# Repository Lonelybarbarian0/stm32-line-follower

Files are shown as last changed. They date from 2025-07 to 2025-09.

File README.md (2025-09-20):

# stm32-line-follower
An advanced line follower based on STM32F446RE. This design consists of 12 Analog IR sensors (CNY70) , a dual H-bridge driver (TB6612FNG) , has I2C ports for oled display , push buttons , 12V battery accomodation , SWD , and debug UART ports for programming and debugging the microcontroller.
Has two voltage regulators for 3V3 and 5V.

It has mounting holes for caster wheel (15mm) , specifically this one: https://robu.in/product/mini-3pi-car-n20-caster-robot-ball-wheel/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

It also has mounting holes for adding both N20 (18mm) as well as 14mm * 16mm motor brackets like:https://roboticsdna.in/product/25mm-dc-gear-motor-block-l-shape-motor-bracket/?src=google&kwd=&adgroup={adgroup}&device=c&campaign={campaign}&adgroup={adgroup}&keyword=&matchtype=&gad_source=1&gad_campaignid=22793537991&gbraid=0AAAAAC-xzeH1j9IDTkCSxU-zOjWUDu6ZW&gclid=Cj0KCQjwm93DBhD_ARIsADR_DjG1hGDh40R1bVBjp1YW7XD5IBcDVYip5r4QT6sreYXs5M1MaoTtmnkaAhj5EALw_wcB

Features power on led , a power on switch etc...

SIDE VIEW:
line_follow_stm_NV

BACK VIEW:
line_follow_stm_BV

PIN CONFIG:
line_follow

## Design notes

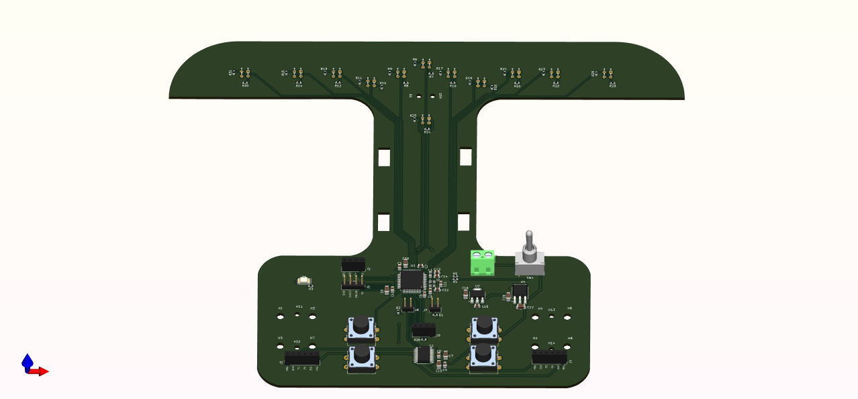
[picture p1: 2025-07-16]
stm32 line follower/line_follow_stm_NV.png

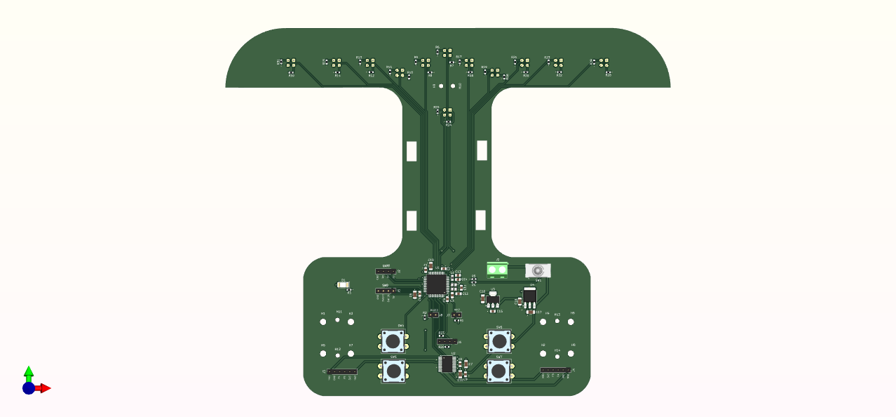
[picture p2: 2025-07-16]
stm32 line follower/line_follow_stm_FV.png

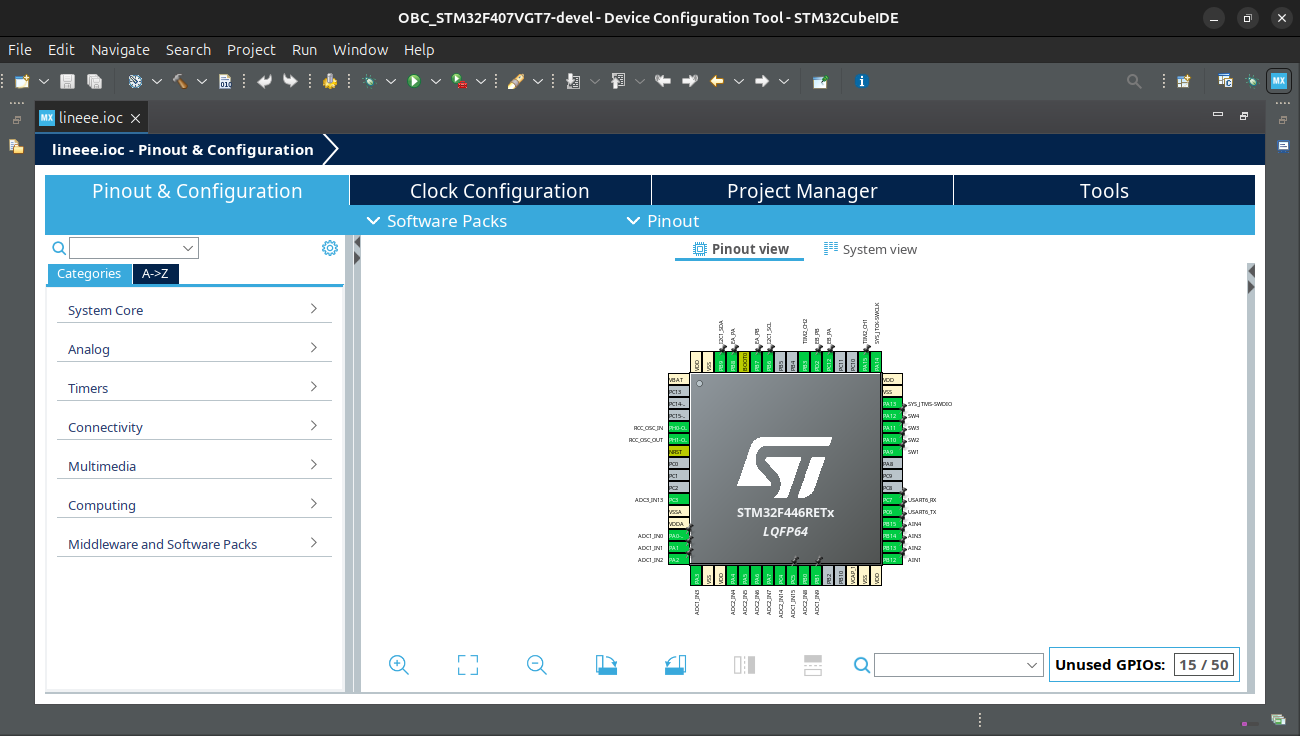
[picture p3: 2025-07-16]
stm32 line follower/line_follow.png

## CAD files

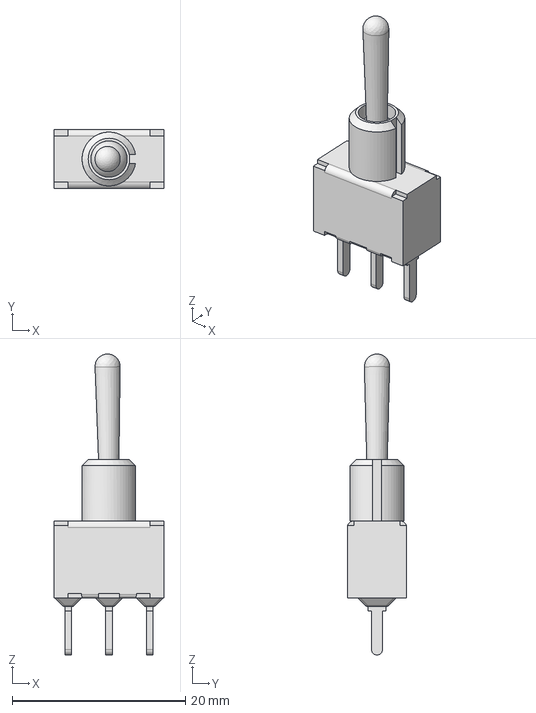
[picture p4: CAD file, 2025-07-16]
stm32 line follower/line_follow_stm/footprint_libraries/100SP1T1B4M2QE/100SP1T1B4M2QE.step
12.7 x 6.86 x 34.8 mm

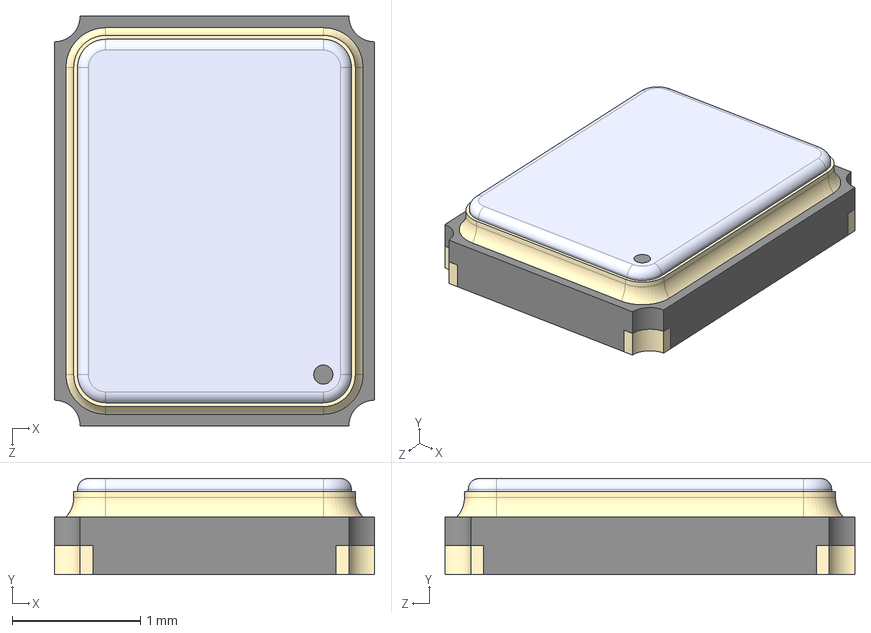
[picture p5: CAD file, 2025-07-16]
stm32 line follower/line_follow_stm/footprint_libraries/C3E_8_000_18_1020_X_R/C3E-8.000-18-1020-X-R.step
2.50 x 0.75 x 3.20 mm

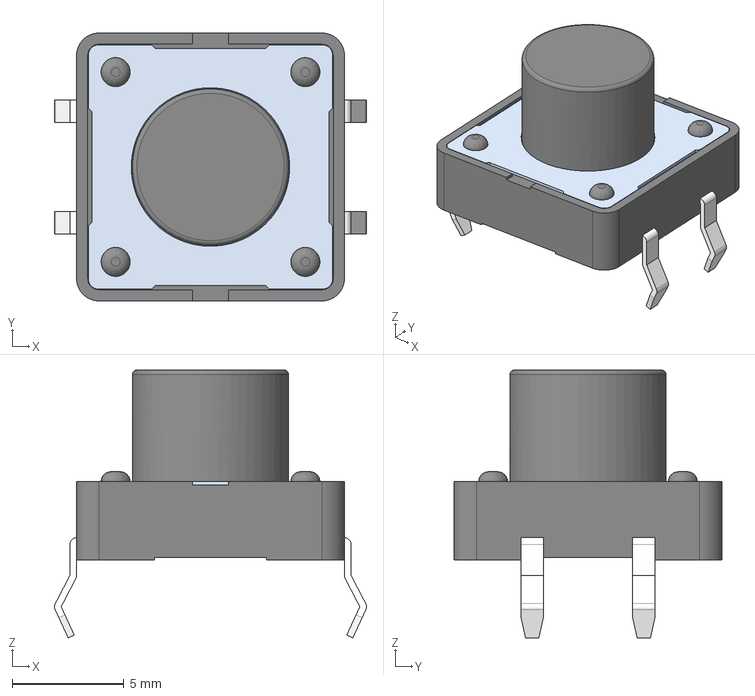
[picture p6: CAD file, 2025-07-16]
stm32 line follower/line_follow_stm/3D Models/430476085716+(rev1).stp
14.0 x 12.0 x 12.0 mm

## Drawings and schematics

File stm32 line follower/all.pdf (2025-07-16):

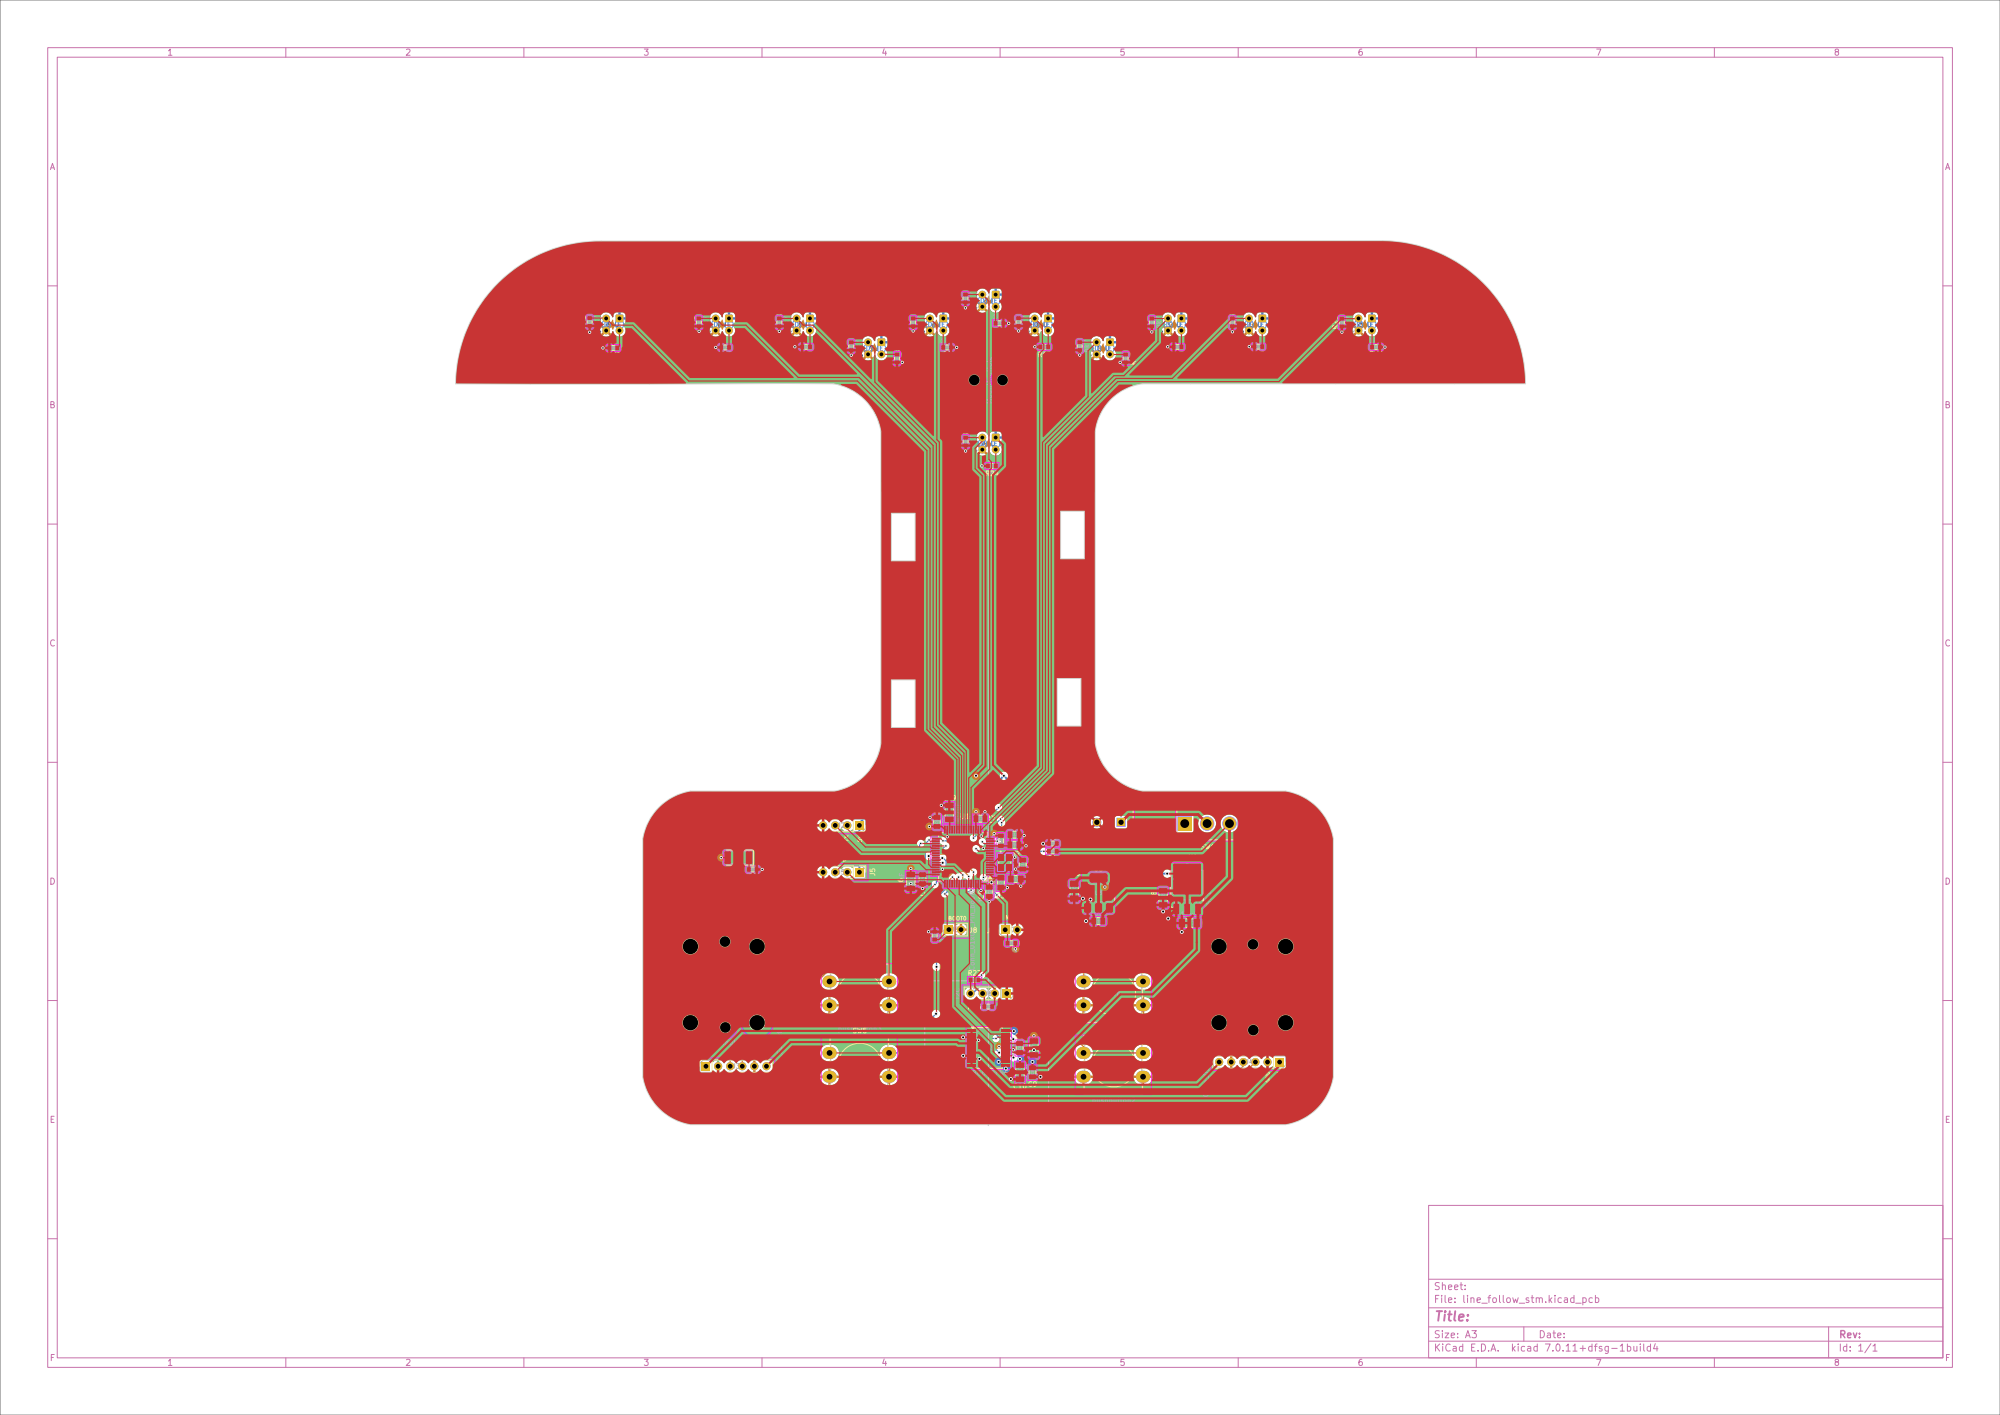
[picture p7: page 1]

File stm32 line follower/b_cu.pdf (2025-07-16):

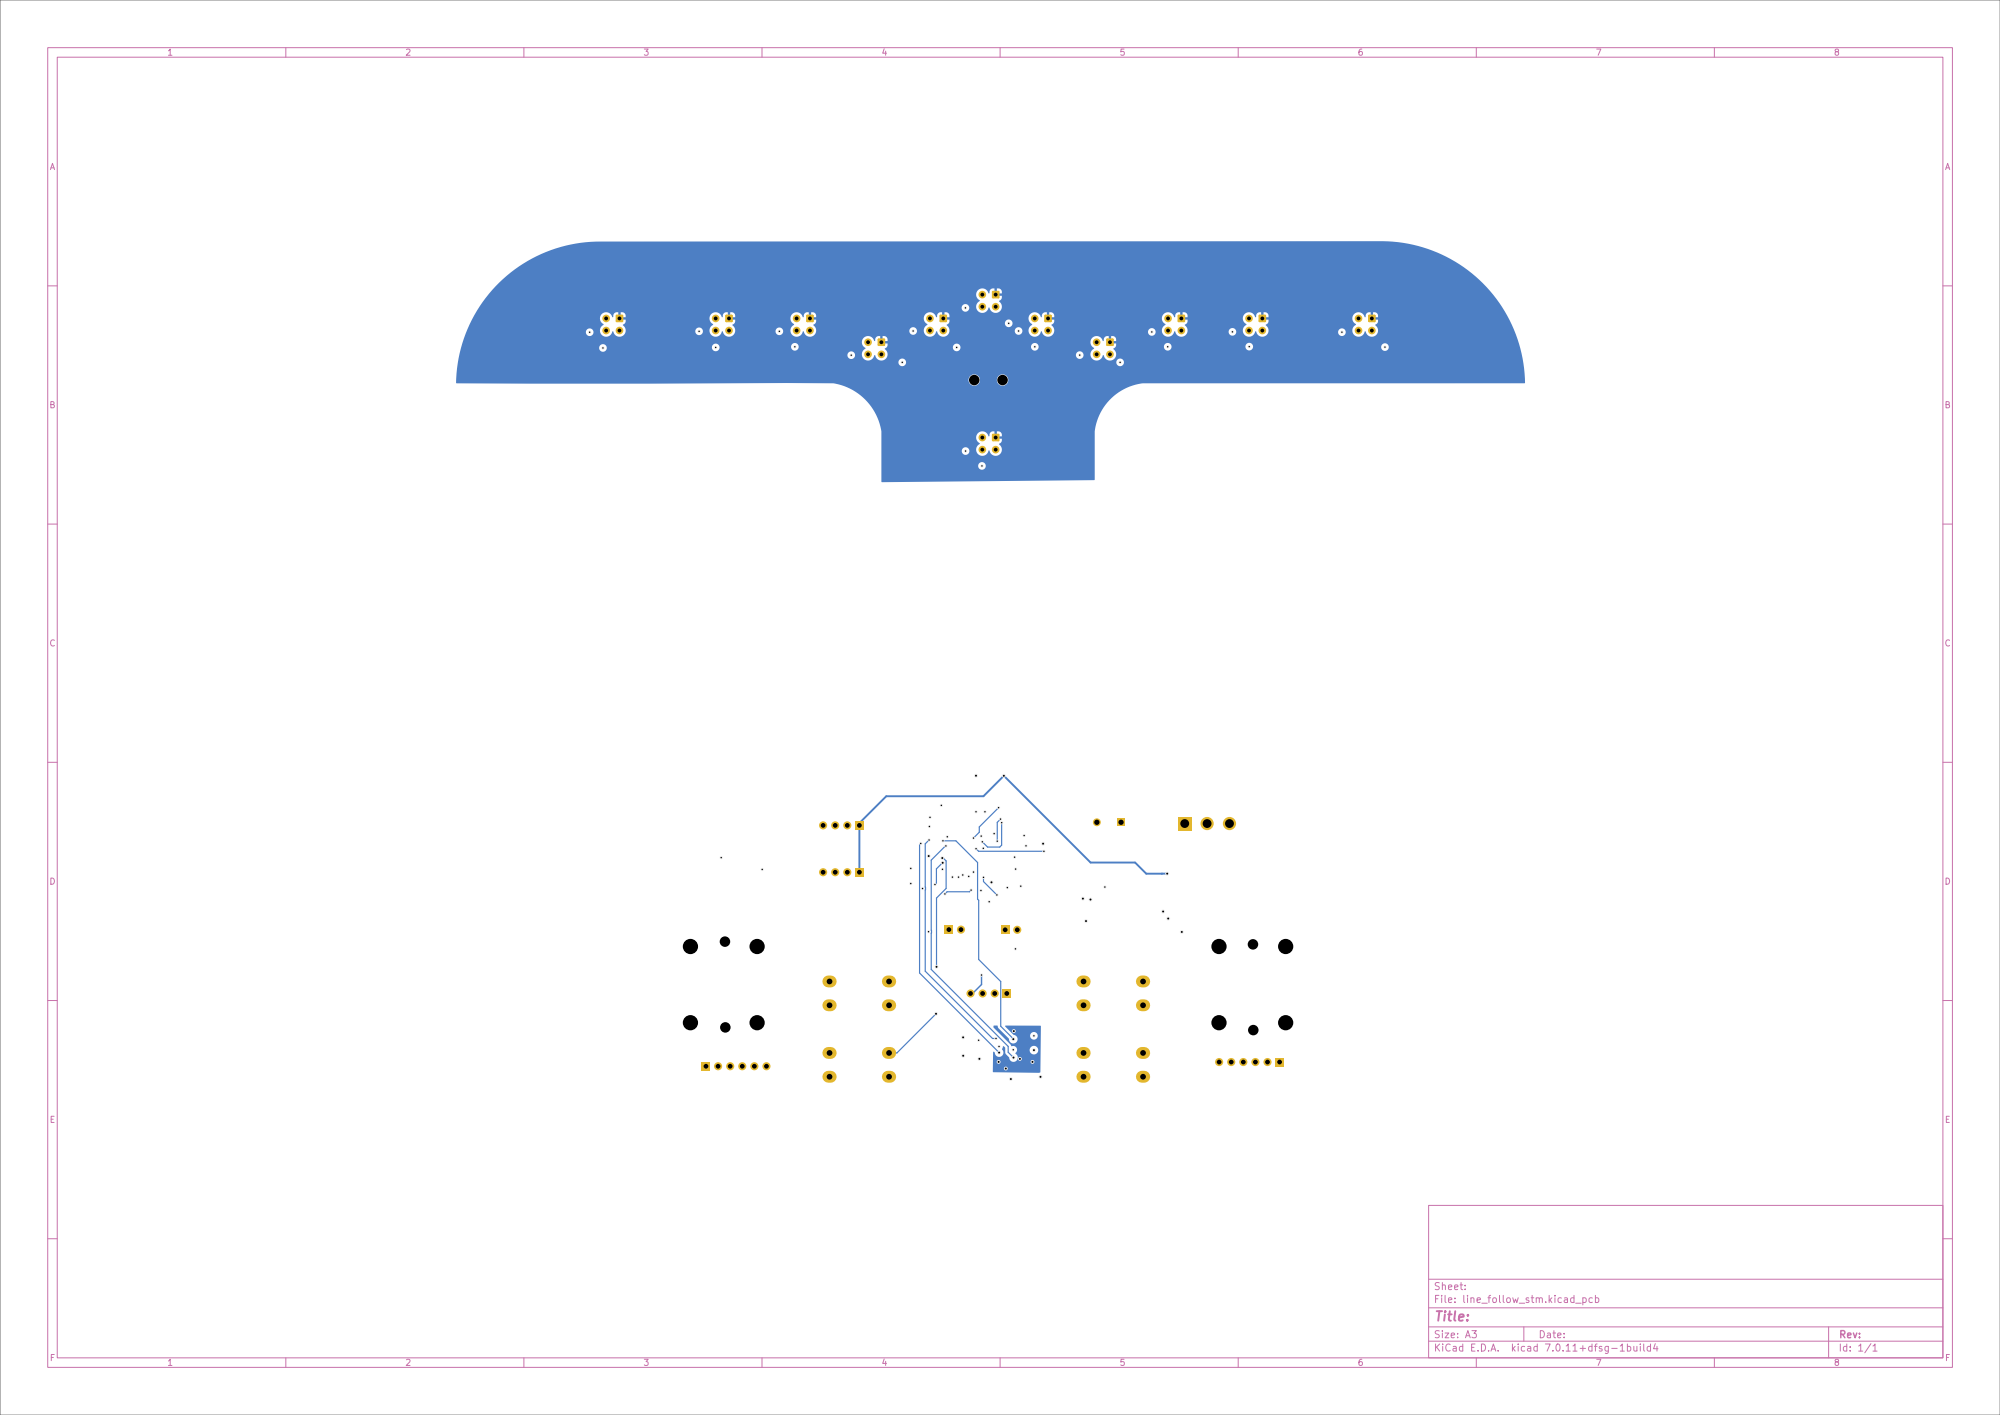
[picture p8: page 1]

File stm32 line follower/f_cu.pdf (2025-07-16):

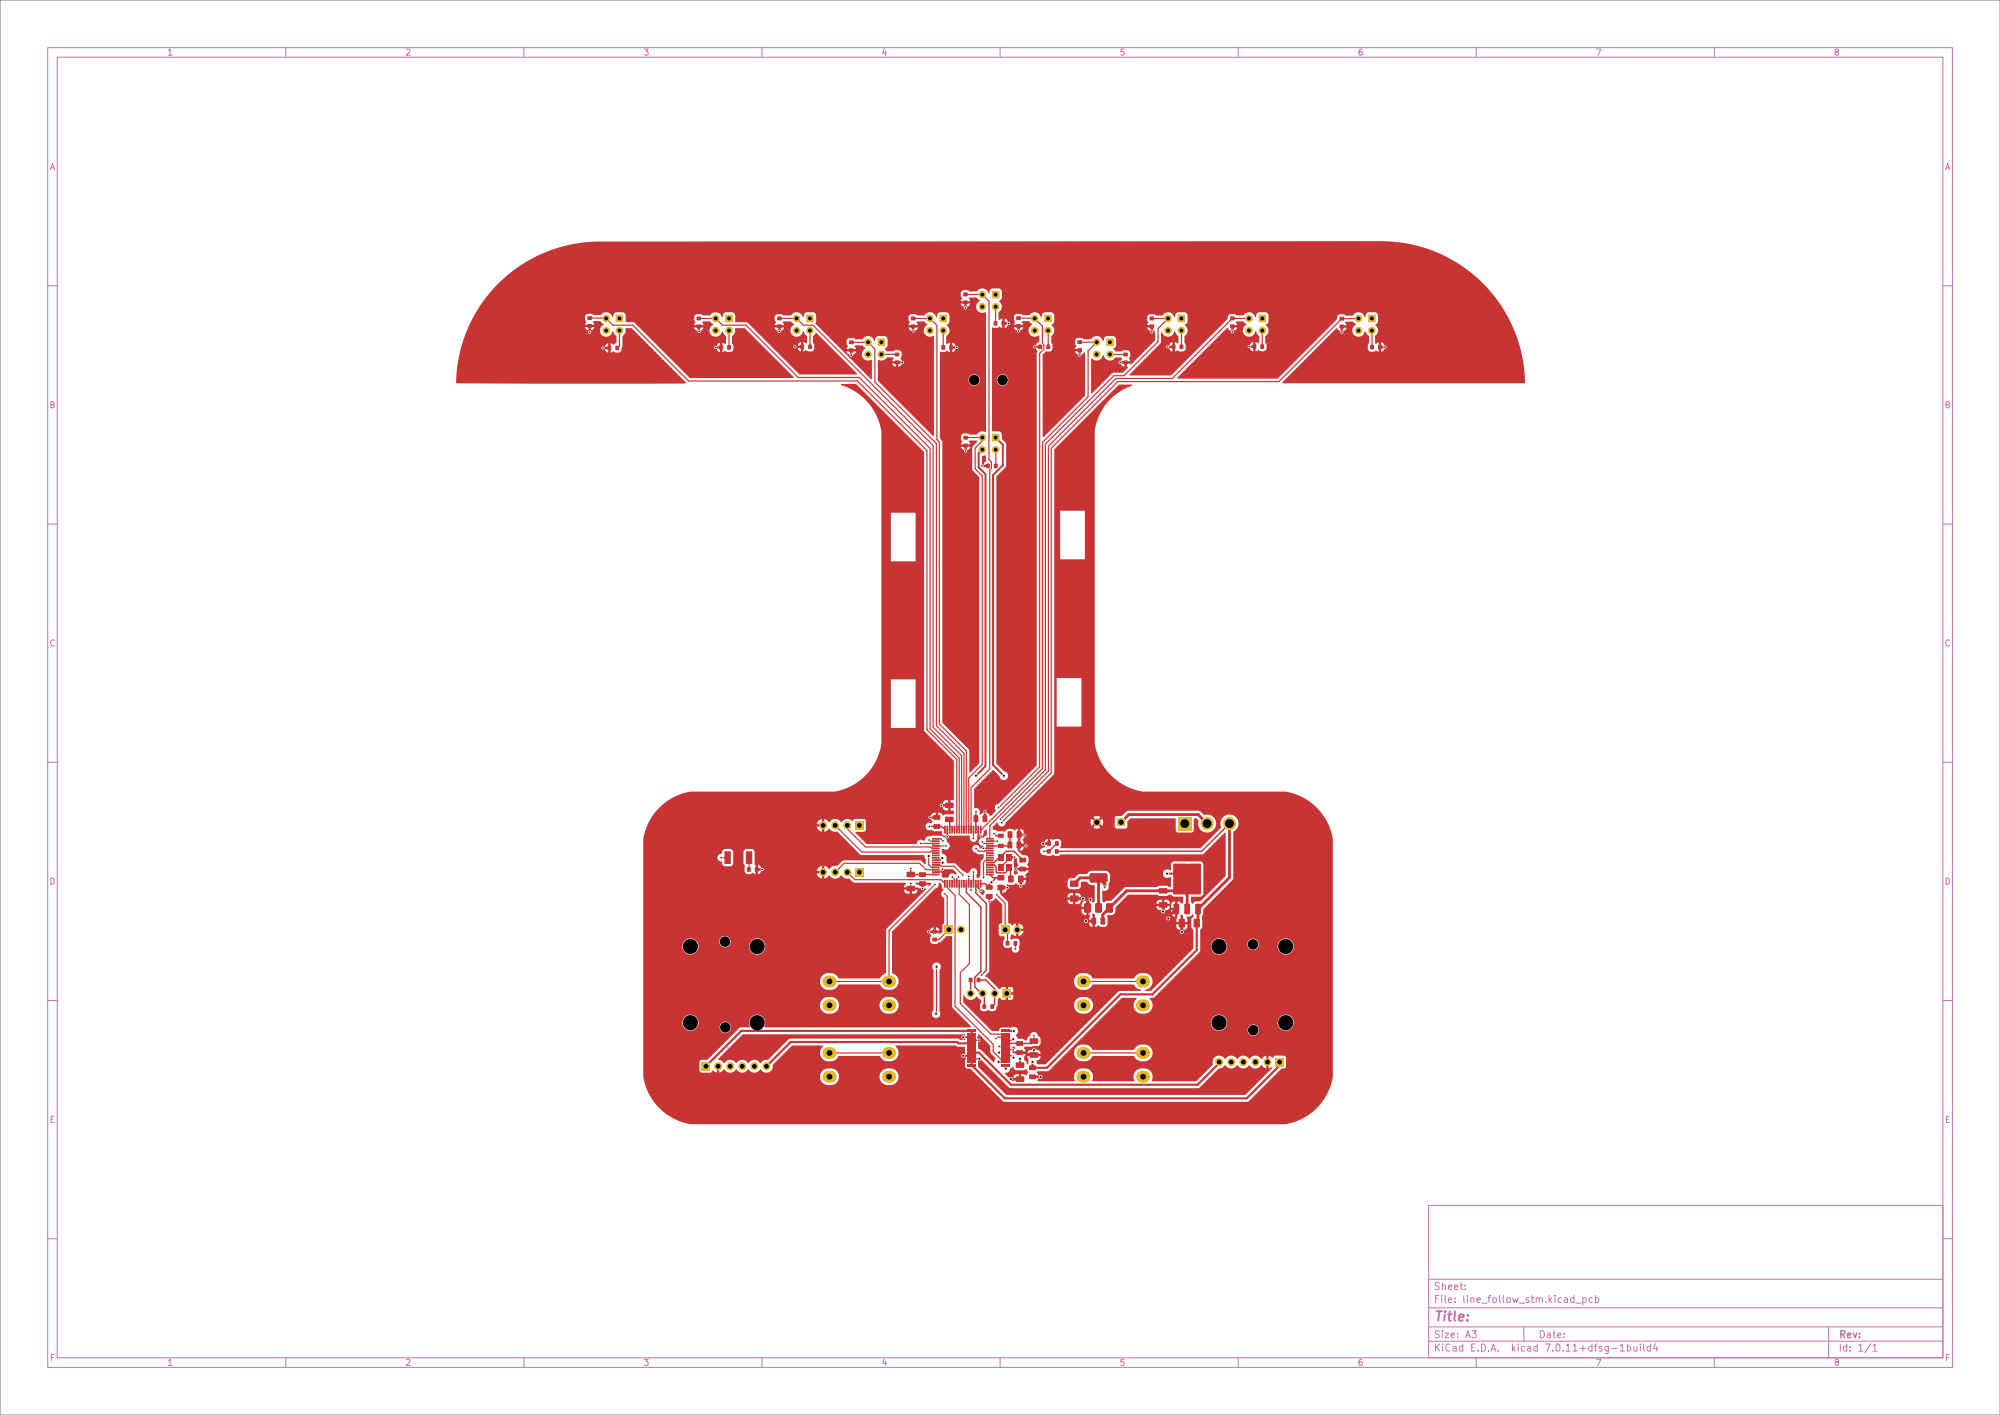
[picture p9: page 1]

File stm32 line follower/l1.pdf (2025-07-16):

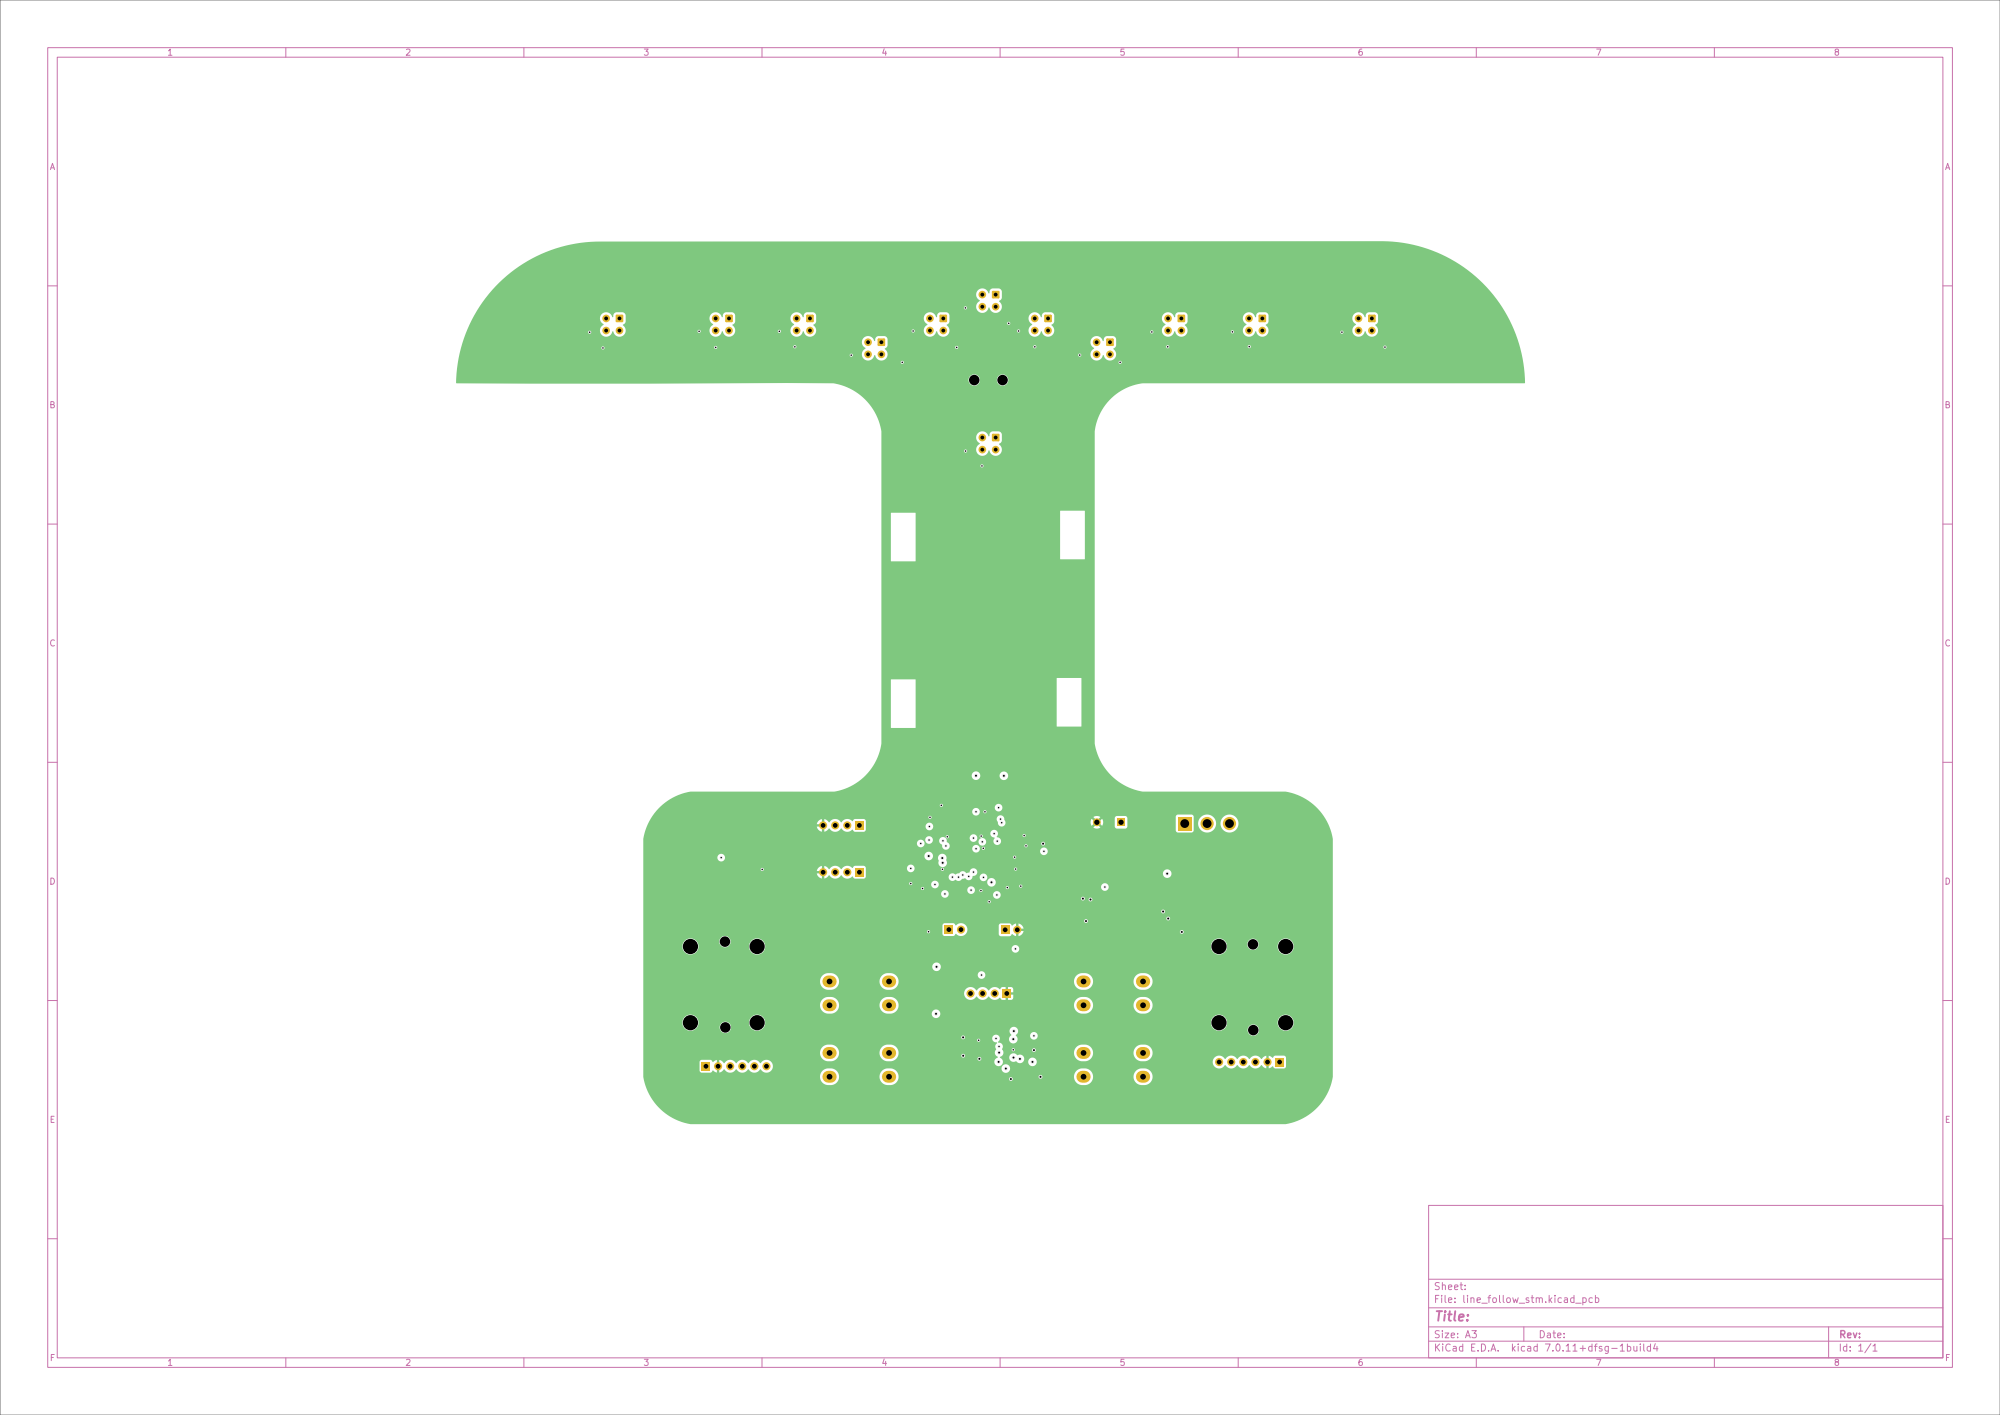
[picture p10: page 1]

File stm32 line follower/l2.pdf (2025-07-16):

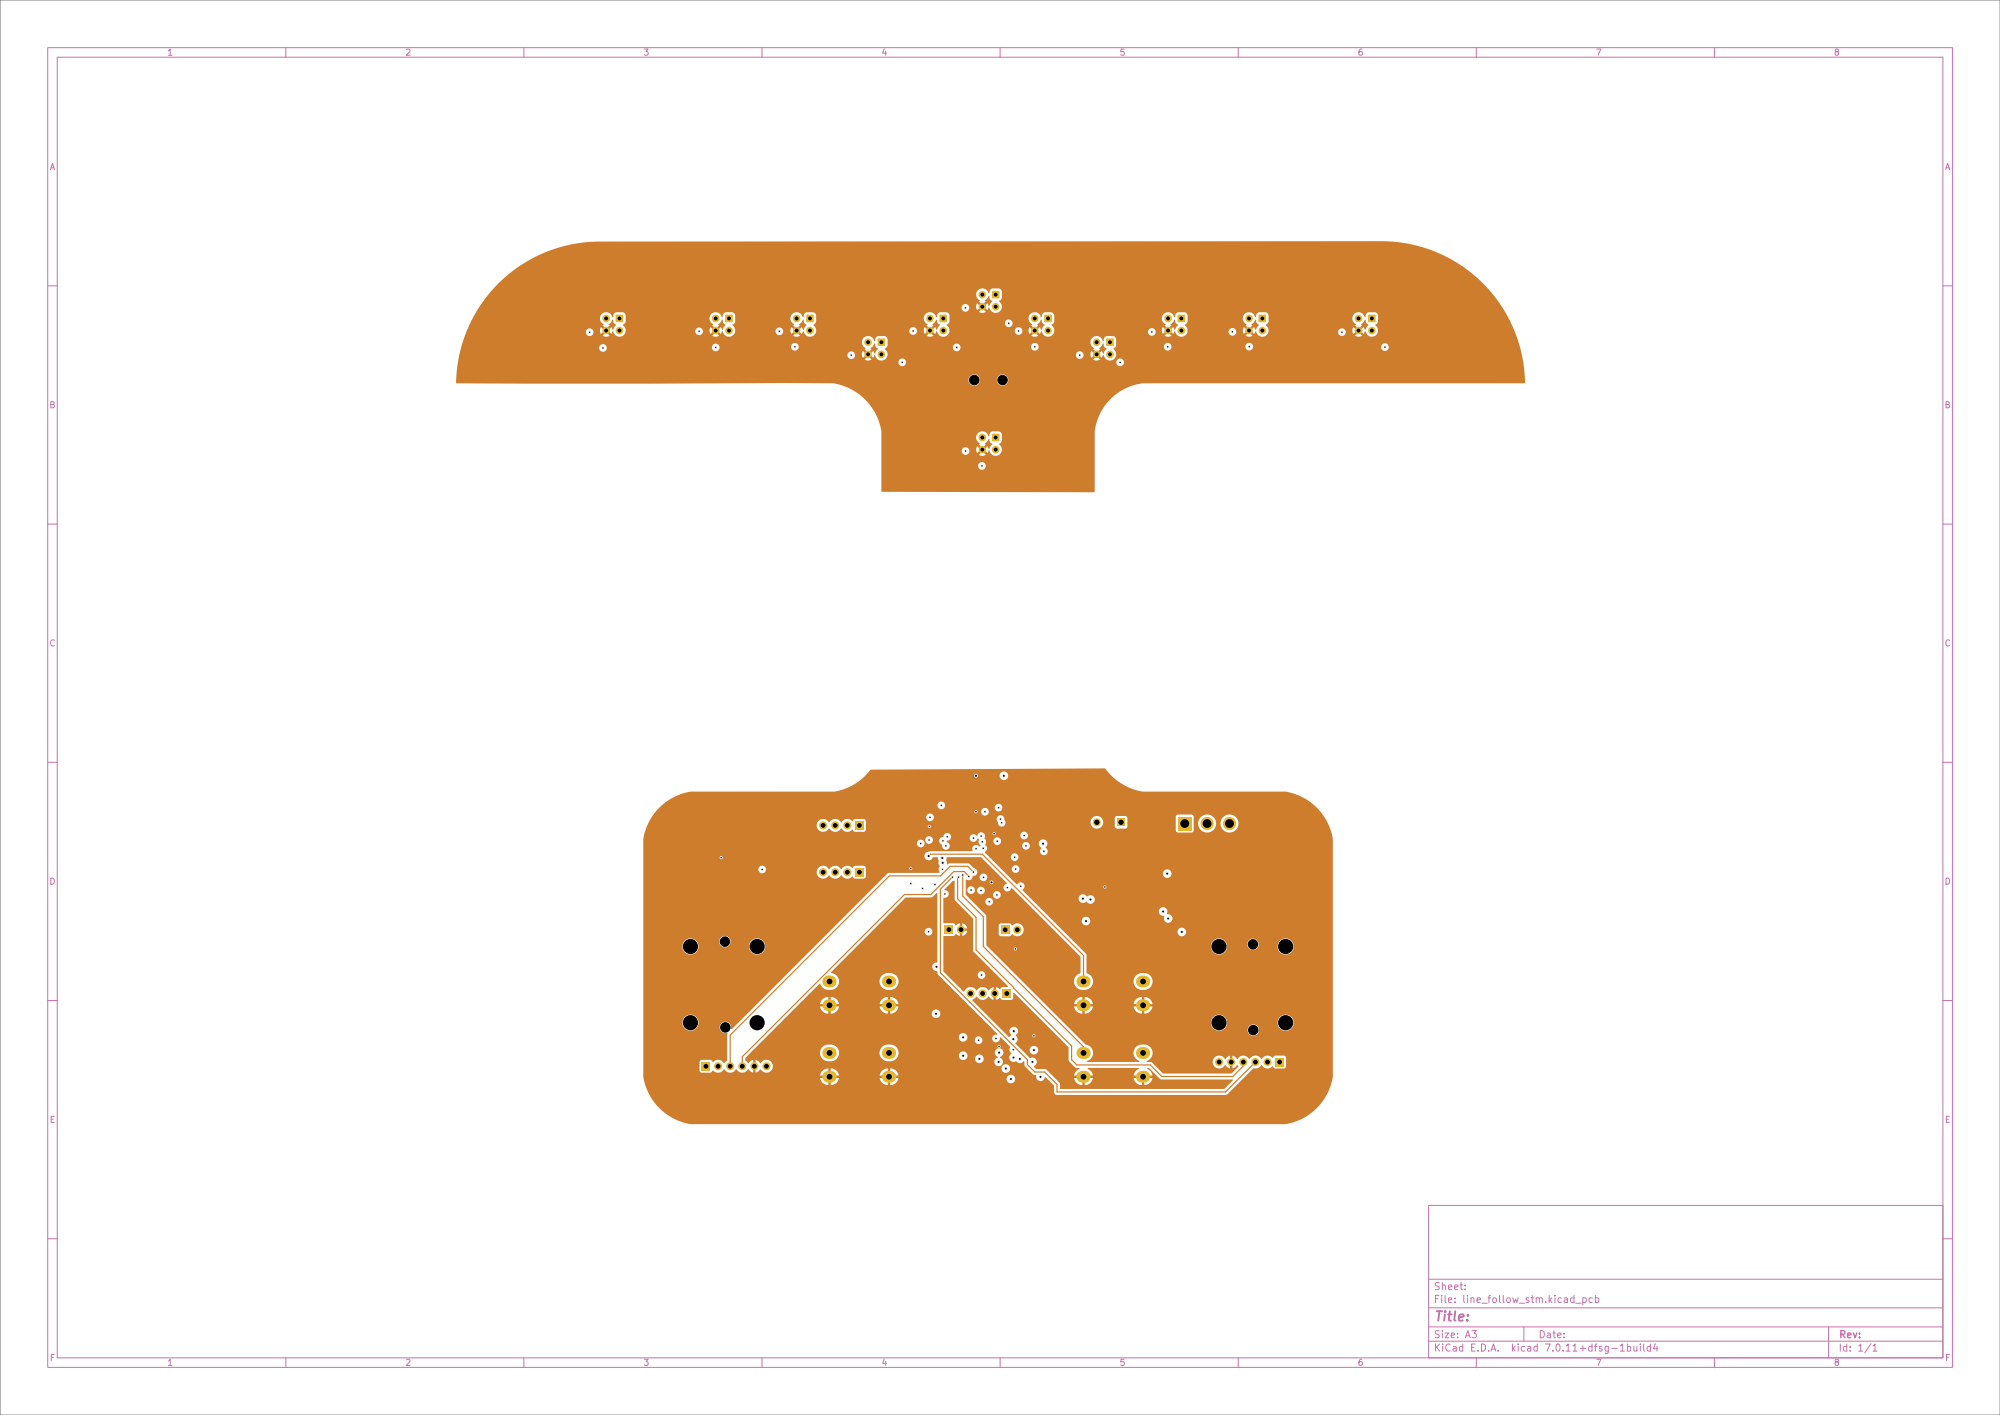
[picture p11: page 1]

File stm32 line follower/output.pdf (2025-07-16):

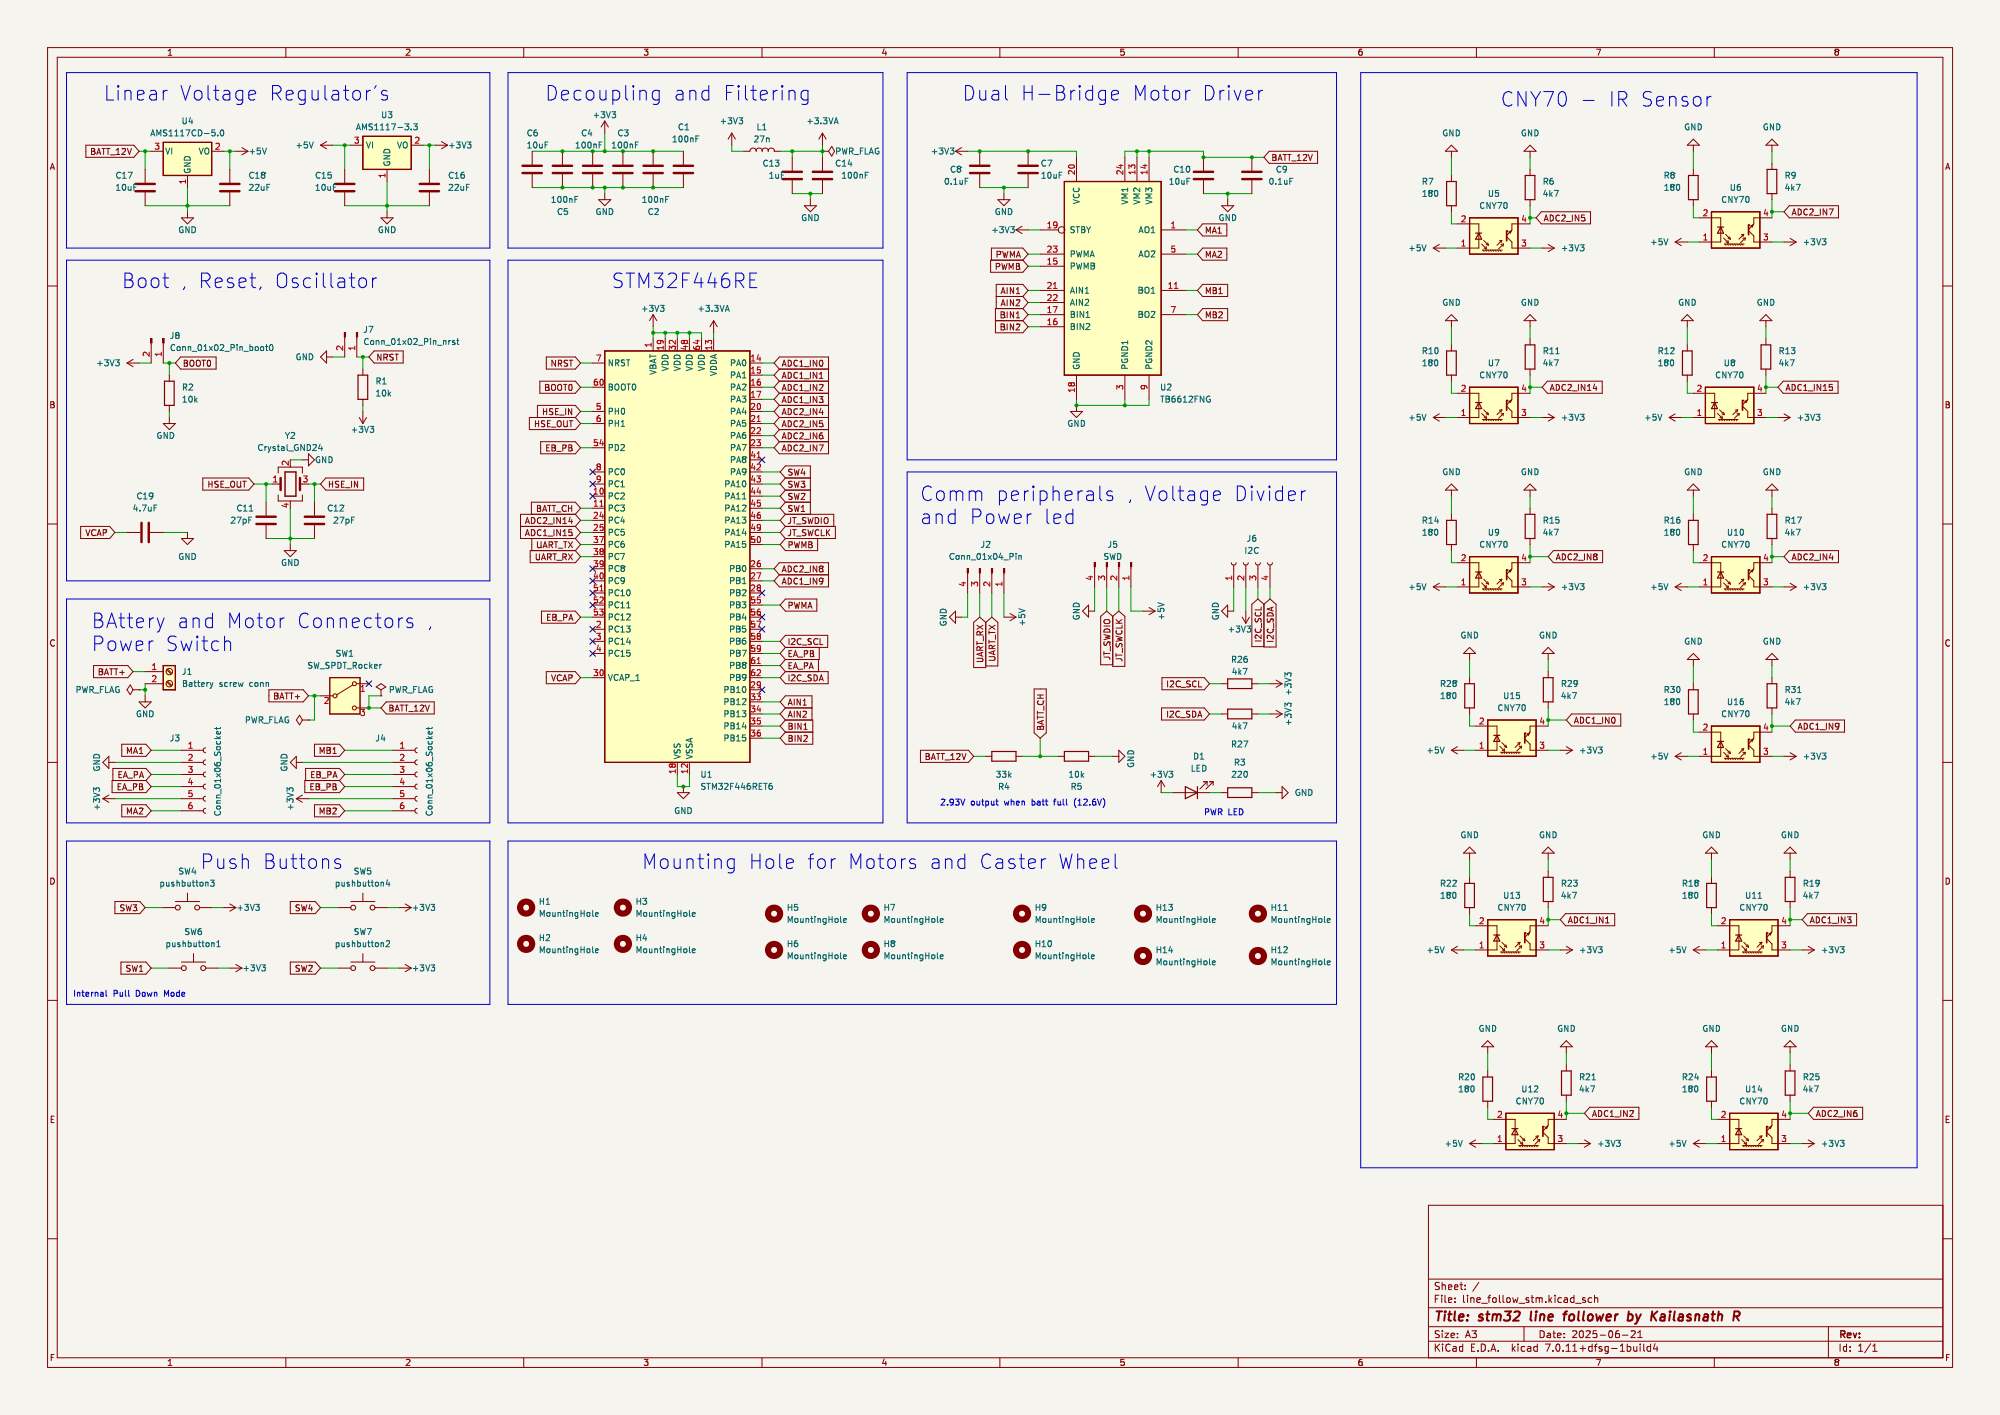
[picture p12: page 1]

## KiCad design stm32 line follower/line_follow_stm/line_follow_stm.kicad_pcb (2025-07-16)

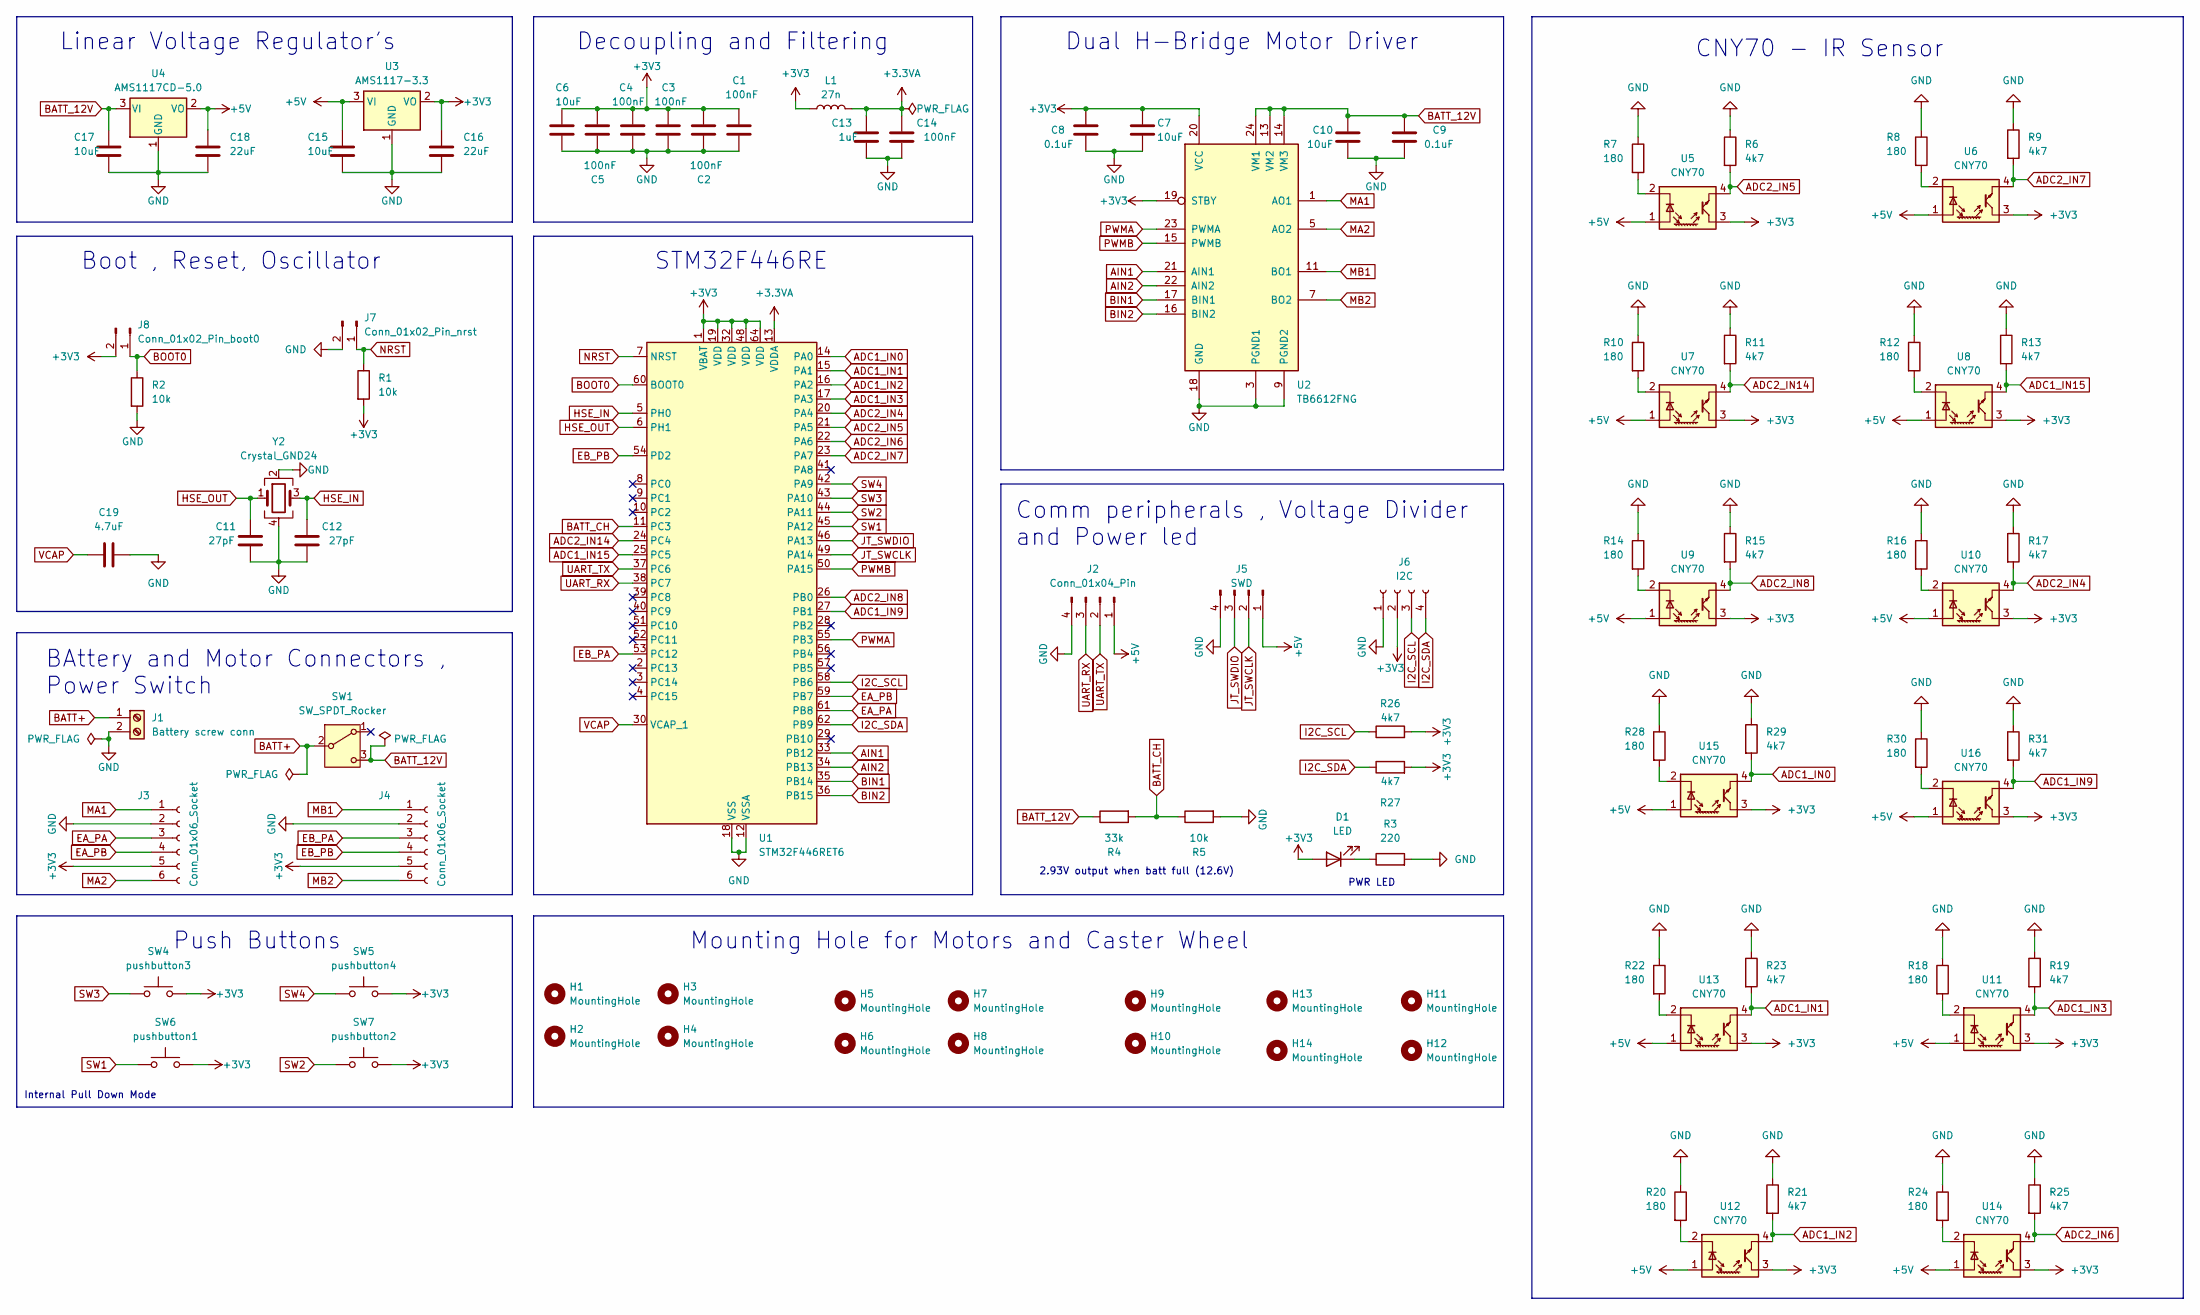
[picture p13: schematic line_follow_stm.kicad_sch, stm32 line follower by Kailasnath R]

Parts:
C1, C2, C4, C5, C14: 100nF; C_0805_2012Metric
C3: 100nF; C_0805_2012Metric_Pad1.18x1.45mm_HandSolder
C6, C7, C10: 10uF; C_1206_3216Metric
C8, C9: 0.1uF; C_0805_2012Metric
C11: 27pF; C_0805_2012Metric
C12: 27pF; C_0805_2012Metric_Pad1.18x1.45mm_HandSolder
C13: 1uF; C_0805_2012Metric
C15: 10uF; C_0805_2012Metric
C16: 22uF; C_1206_3216Metric_Pad1.33x1.80mm_HandSolder
C17: 10uF; C_1206_3216Metric_Pad1.33x1.80mm_HandSolder
C18: 22uF; C_1206_3216Metric
C19: 4.7uF; C_1206_3216Metric
D1: LED; LED_2010_5025Metric
H1, H2, H3, H4, H5, H6, H7, H8: MountingHole; MountingHole_3.2mm_M3
H9, H10, H11, H12, H13, H14: MountingHole; MountingHole_2.2mm_M2
J1: Battery screw conn; TE_282837-2
J2: Conn_01x04_Pin; PinSocket_1x04_P2.54mm_Vertical
J3, J4: Conn_01x06_Socket; PinSocket_1x06_P2.54mm_Vertical
J5: SWD; PinHeader_1x04_P2.54mm_Vertical
J6: I2C; PinSocket_1x04_P2.54mm_Vertical
J7: Conn_01x02_Pin_nrst; PinHeader_1x02_P2.54mm_Vertical
J8: Conn_01x02_Pin_boot0; PinHeader_1x02_P2.54mm_Vertical
L1: 27n; L_0805_2012Metric
R1, R2, R5: 10k; R_0603_1608Metric
R3: 220; R_0603_1608Metric
R4: 33k; R_0603_1608Metric
R6, R9, R11, R13, R15, R17, R19, R21, R23, R25, R26, R27, R29, R31: 4k7; R_0603_1608Metric
R7, R8, R10, R12, R14, R16, R18, R20, R22, R24, R28, R30: 180; R_0603_1608Metric
SW1: SW_SPDT_Rocker; SW_100SP1T1B4M2QE
SW4: pushbutton3; SW_PUSH-12mm_Wuerth-430476085716
SW5: pushbutton4; SW_PUSH-12mm_Wuerth-430476085716
SW6: pushbutton1; SW_PUSH-12mm_Wuerth-430476085716
SW7: pushbutton2; SW_PUSH-12mm_Wuerth-430476085716
U1: STM32F446RET6; LQFP-64_10x10mm_P0.5mm
U2: TB6612FNG; SSOP-24_5.3x8.2mm_P0.65mm
U3: AMS1117-3.3; SOT-223-3_TabPin2
U4: AMS1117CD-5.0; TO-252-3_TabPin2
U5, U6, U7, U8, U9, U10, U11, U12, U13, U14, U15, U16: CNY70; Vishay_CNY70
Y2: Crystal_GND24; XTAL_C3E-8.000-18-1020-X-R

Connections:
+3.3VA: C13.1, C14.1, L1.2, U1.13 (VDDA)
+3V3: C1.1, C2.1, C3.1, C4.1, C5.1, C6.1, C7.1, C8.1, C16.1, D1.2 (A), J3.5, J4.5, J6.2, J8.2, L1.1, R1.2, R26.2, R27.2, SW4.2, SW5.2, SW6.2, SW7.2, U1.1 (VBAT), U1.19 (VDD), U1.32 (VDD), U1.48 (VDD), U1.64 (VDD), U2.19 (STBY), U2.20 (VCC), U3.2 (VO), U5.3 (C), U6.3 (C), U7.3 (C), U8.3 (C), U9.3 (C), U10.3 (C), U11.3 (C), U12.3 (C), U13.3 (C), U14.3 (C), U15.3 (C), U16.3 (C)
+5V: C15.1, C18.1, J2.1, J5.1, U3.3 (VI), U4.2 (VO), U5.1 (A), U6.1 (A), U7.1 (A), U8.1 (A), U9.1 (A), U10.1 (A), U11.1 (A), U12.1 (A), U13.1 (A), U14.1 (A), U15.1 (A), U16.1 (A)
ADC1_IN0: R29.2, U1.14 (PA0), U15.4 (E)
ADC1_IN1: R23.2, U1.15 (PA1), U13.4 (E)
ADC1_IN2: R21.2, U1.16 (PA2), U12.4 (E)
ADC1_IN3: R19.2, U1.17 (PA3), U11.4 (E)
ADC1_IN9: R31.2, U1.27 (PB1), U16.4 (E)
ADC1_IN15: R13.2, U1.25 (PC5), U8.4 (E)
ADC2_IN4: R17.2, U1.20 (PA4), U10.4 (E)
ADC2_IN5: R6.2, U1.21 (PA5), U5.4 (E)
ADC2_IN6: R25.2, U1.22 (PA6), U14.4 (E)
ADC2_IN7: R9.2, U1.23 (PA7), U6.4 (E)
ADC2_IN8: R15.2, U1.26 (PB0), U9.4 (E)
ADC2_IN14: R11.2, U1.24 (PC4), U7.4 (E)
AIN1: U1.33 (PB12), U2.21 (AIN1)
AIN2: U1.34 (PB13), U2.22 (AIN2)
BATT+: J1.1, SW1.2 (B)
BATT_12V: C9.1, C10.1, C17.1, R4.1, SW1.3 (C), U2.13 (VM2), U2.14 (VM3), U2.24 (VM1), U4.3 (VI)
BATT_CH: R4.2, R5.1, U1.11 (PC3)
BIN1: U1.35 (PB14), U2.17 (BIN1)
BIN2: U1.36 (PB15), U2.16 (BIN2)
BOOT0: J8.1, R2.1, U1.60 (BOOT0)
EA_PA: J3.3, U1.61 (PB8)
EA_PB: J3.4, U1.59 (PB7)
EB_PA: J4.3, U1.53 (PC12)
EB_PB: J4.4, U1.54 (PD2)
GND: C1.2, C2.2, C3.2, C4.2, C5.2, C6.2, C7.2, C8.2, C9.2, C10.2, C11.2, C12.2, C13.2, C14.2, C15.2, C16.2, C17.2, C18.2, C19.2, J1.2, J2.4, J3.2, J4.2, J5.4, J6.1, J7.2, R2.2, R3.2, R5.2, R6.1, R7.1, R8.1, R9.1, R10.1, R11.1, R12.1, R13.1, R14.1, R15.1, R16.1, R17.1, R18.1, R19.1, R20.1, R21.1, R22.1, R23.1, R24.1, R25.1, R28.1, R29.1, R30.1, R31.1, U1.12 (VSSA), U1.18 (VSS), U1.31 (VSS), U1.47 (VSS), U1.63 (VSS), U2.3 (PGND1), U2.4 (PGND1), U2.9 (PGND2), U2.10 (PGND2), U2.18 (GND), U3.1 (GND), U4.1 (GND), Y2.2, Y2.4
HSE_IN: C12.1, U1.5 (PH0), Y2.3
HSE_OUT: C11.1, U1.6 (PH1), Y2.1
I2C_SCL: J6.3, R26.1, U1.58 (PB6)
I2C_SDA: J6.4, R27.1, U1.62 (PB9)
JT_SWCLK: J5.2, U1.49 (PA14)
JT_SWDIO: J5.3, U1.46 (PA13)
MA1: J3.1, U2.1 (AO1), U2.2 (AO1)
MA2: J3.6, U2.5 (AO2), U2.6 (AO2)
MB1: J4.1, U2.11 (BO1), U2.12 (BO1)
MB2: J4.6, U2.7 (BO2), U2.8 (BO2)
NRST: J7.1, R1.1, U1.7 (NRST)
unnamed: D1.1 (K), R3.1
unnamed: R7.2, U5.2 (K)
unnamed: R8.2, U6.2 (K)
unnamed: R10.2, U7.2 (K)
unnamed: R12.2, U8.2 (K)
unnamed: R14.2, U9.2 (K)
unnamed: R16.2, U10.2 (K)
unnamed: R18.2, U11.2 (K)
unnamed: R20.2, U12.2 (K)
unnamed: R22.2, U13.2 (K)
unnamed: R24.2, U14.2 (K)
unnamed: R28.2, U15.2 (K)
unnamed: R30.2, U16.2 (K)
PWMA: U1.55 (PB3), U2.23 (PWMA)
PWMB: U1.50 (PA15), U2.15 (PWMB)
SW1: SW6.1, U1.45 (PA12)
SW2: SW7.1, U1.44 (PA11)
SW3: SW4.1, U1.43 (PA10)
SW4: SW5.1, U1.42 (PA9)
UART_RX: J2.3, U1.38 (PC7)
UART_TX: J2.2, U1.37 (PC6)
VCAP: C19.1, U1.30 (VCAP_1)

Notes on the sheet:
CNY70 - IR Sensor
Linear Voltage Regulator's
BAttery and Motor Connectors , Power Switch
STM32F446RE
Comm peripherals , Voltage Divider and Power led
Dual H-Bridge Motor Driver
Decoupling and Filtering
Internal Pull Down Mode
2.93V output when batt full (12.6V)
Mounting Hole for Motors and Caster Wheel
Boot , Reset, Oscillator
PWR LED
Push Buttons

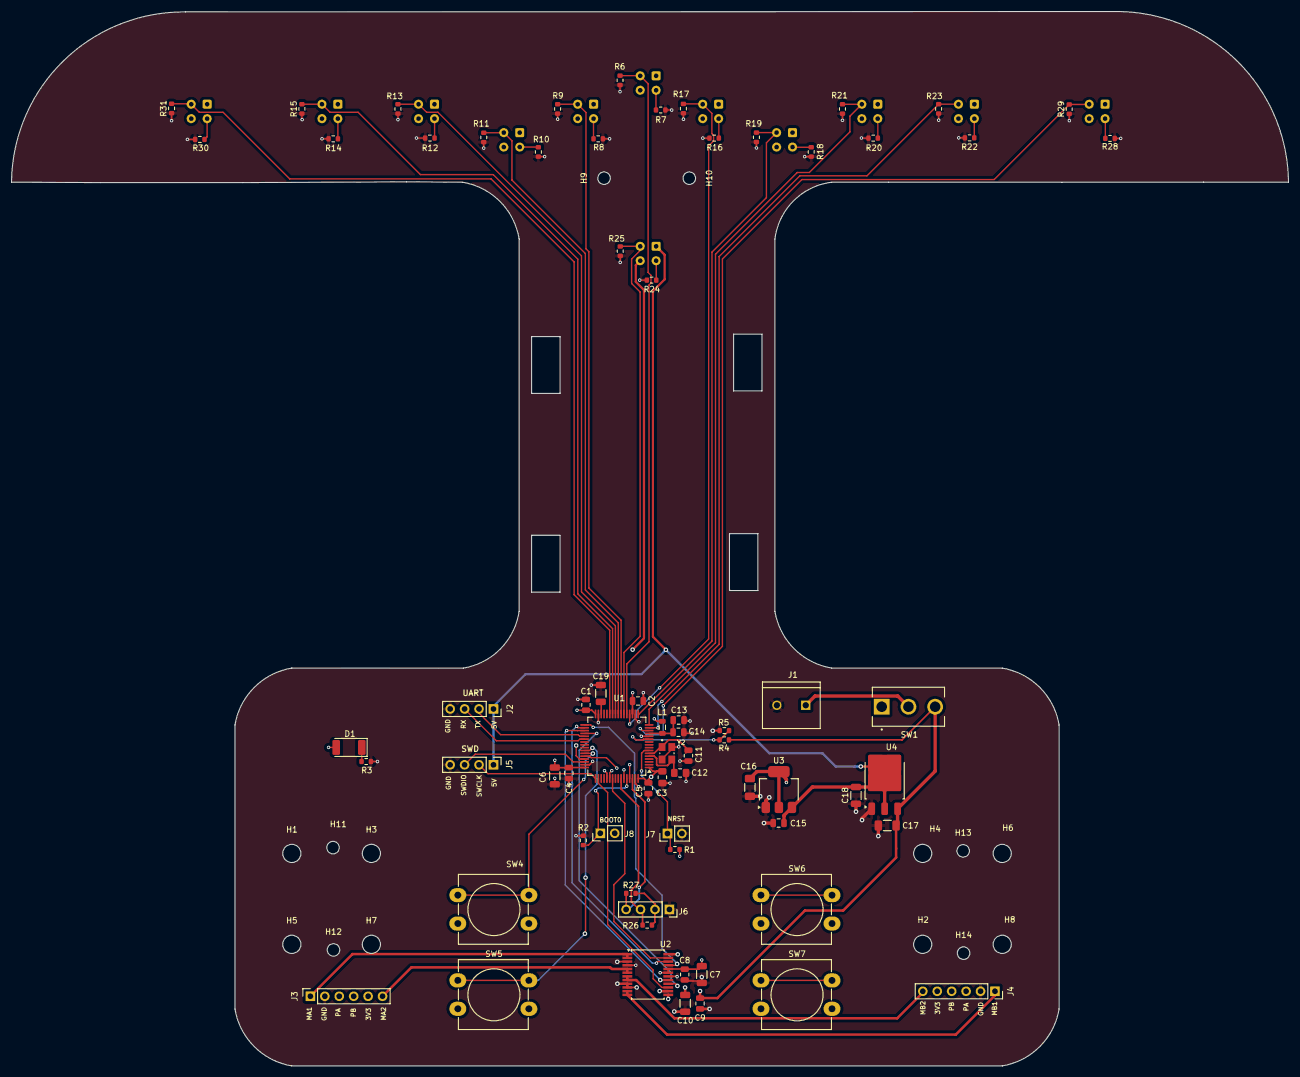
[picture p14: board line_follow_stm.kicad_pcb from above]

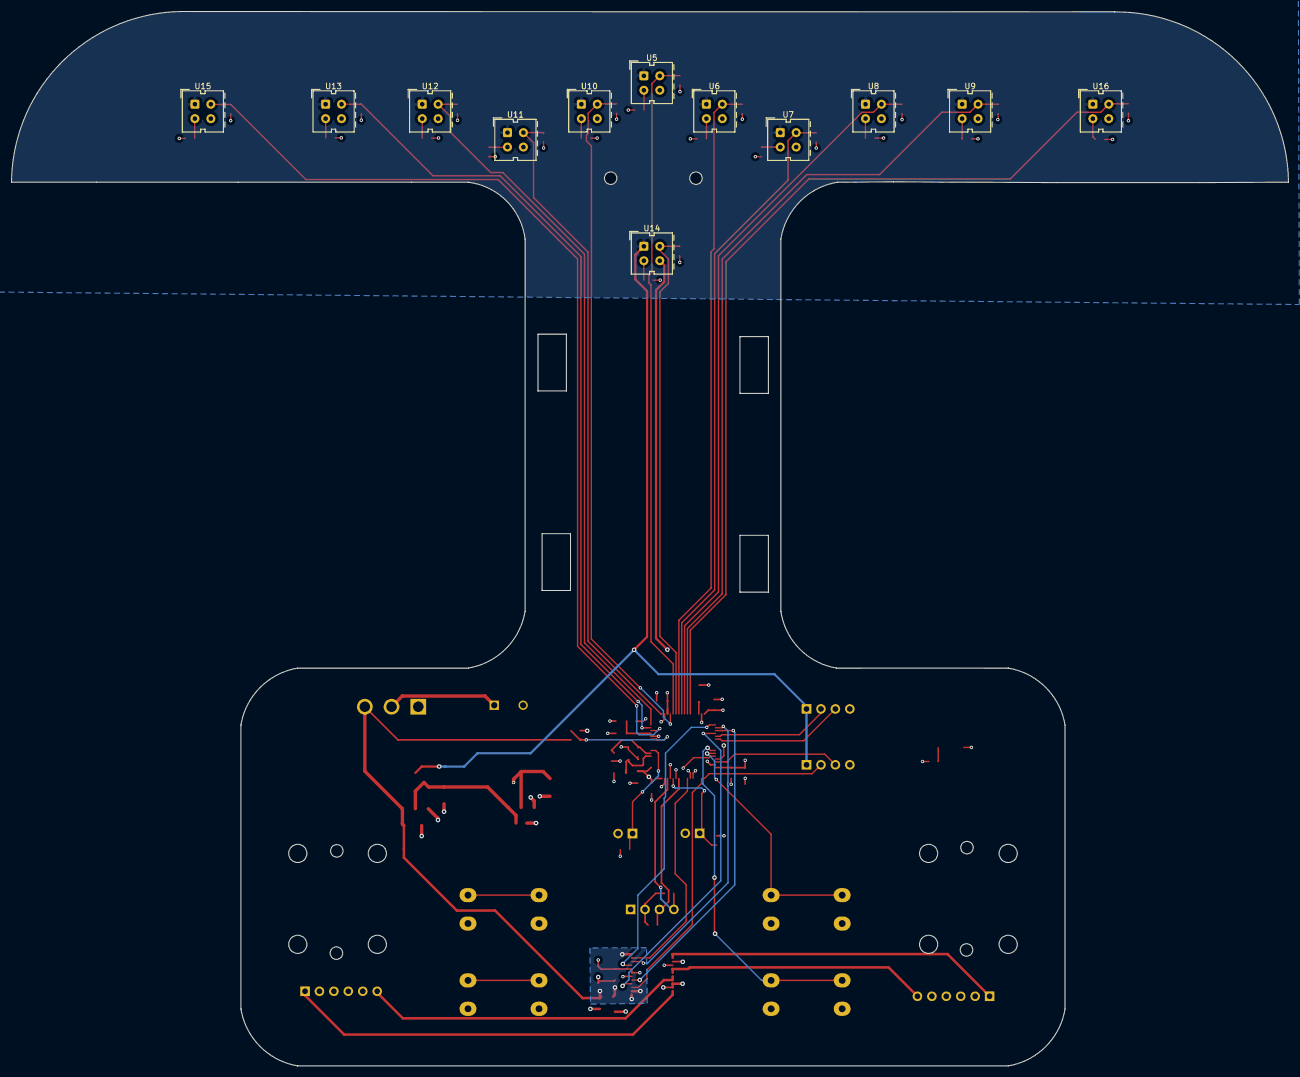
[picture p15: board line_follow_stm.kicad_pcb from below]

Board: 4 copper layers, 224.7 x 185.5 mm, 96 parts (12 on the bottom side), 61 nets.

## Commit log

2025-07-16 V 1.0
    First Version
    [100SP1T1B4M2QE.step, 430476085716+(rev1).stp, C3E-8.000-18-1020-X-R.step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]
2025-07-16 stm32 line follower
    V 1.0
    [100SP1T1B4M2QE.step, 430476085716+(rev1).stp, C3E-8.000-18-1020-X-R.step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]
